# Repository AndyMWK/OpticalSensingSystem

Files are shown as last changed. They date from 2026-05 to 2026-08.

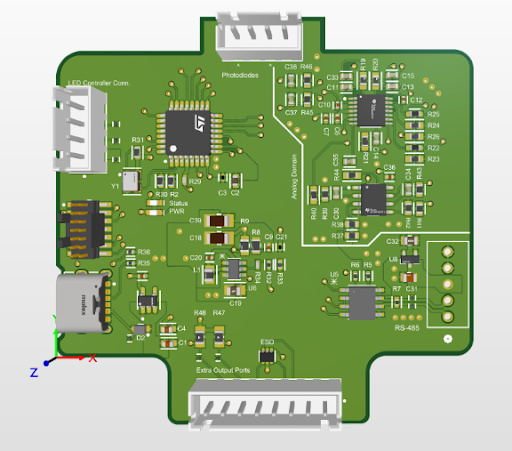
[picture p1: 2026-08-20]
Electrical/board photos/controller pcb view.png

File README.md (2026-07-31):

# IR Sensor Project

An IR proximity/distance sensing system built around dual photodiodes, covering both the electrical hardware and the firmware that drives it.



## Electrical

Designed in Altium ([Electrical/board design](Electrical/board%20design)), the board integrates an IR LED emitter with a dual-photodiode receiver front end, an analog TIA (transimpedance amplifier) stage, USB and RS485 communication interfaces, and power regulation. Analog behavior is validated with SPICE simulations under `Electrical/analog spice simulations`, and datasheets/design docs are kept under `Electrical/Datasheets` and `Electrical/Design Docs`.

## Firmware

The firmware ([Firmware/](Firmware/)) runs on STM32 microcontrollers (mock/dev target: STM32F030R8, production target: STM32G030) and handles ADC acquisition via DMA, EMA low-pass filtering, distance conversion, a finite state machine for sensor status/error handling, and RS485/UART communication. See [Firmware/Doc.md](Firmware/Doc.md) for a detailed architecture overview.

The build tooling is just **STM32CubeMX** for peripheral/HAL code generation, with custom application-level APIs layered on top — no additional framework or RTOS. A Python GUI ([Firmware/gui](Firmware/gui)) is included for interacting with and visualizing sensor data over the host machine.

### Platform support

Currently Windows-only. Linux and macOS support is not implemented yet.

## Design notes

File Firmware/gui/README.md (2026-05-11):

# IR Sensor UART GUI

Basic Python GUI for the `ir_sensor_mock` UART logger.

The mock firmware emits lines like:

```text
PD0 D:1.23 T:45s PD1 D:1.20 T:45s
```

The GUI opens the first available serial port at `9600` baud, shows incoming UART text, and plots the PD0/PD1 distance values.

## Run

```powershell
python -m pip install -r requirements.txt
python ir_sensor_gui.py
```

Use **Refresh** if you connect the board after opening the app.

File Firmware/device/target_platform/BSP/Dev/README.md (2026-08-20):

Device Drivers and APIs for commonly used devices.

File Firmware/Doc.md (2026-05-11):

# IR Sensor Firmware Design Overview

## Introduction

This document provides a brief design overview of the IR sensor firmware implemented in the mock directory (`mock/nucleof030r8/ir_sensor_mock/`). The mock firmware serves as a prototype for the actual target device firmware, utilizing the same core inner workings and architecture. The firmware is designed for STM32F030 microcontroller and simulates IR sensor functionality using two photodiodes.

## Architecture

The firmware follows a modular architecture built on STM32CubeMX-generated code with custom modules for sensor processing. Key components include:

- **Microcontroller**: Mock Device: STM32F030R8 Target Device: STM32G030
- **Peripherals**: ADC (with DMA), UART1/UART2, TIM1/TIM3, RTC
- **Communication**: RS485 for sensor data transmission, UART for logging/debugging
- **Power Management**: Basic HAL-based initialization

## Core Modules

### 1. IR ADC Module (`ir_adc.c`)
- Initializes ADC peripheral with DMA for continuous conversion
- Handles two photodiode channels (PHOTODIODE_1, PHOTODIODE_2)
- Provides callback mechanism for conversion completion
- Packs ADC readings with timestamps into message structures

### 2. IR Processing Module (`ir_processing.c`)
- Converts raw ADC values to distance measurements
- Implements Exponential Moving Average Low Pass Filter (EMA LPF) for noise reduction
- Processes data from FIFO buffers
- Handles sensor status detection (OK, saturated, out of range)

### 3. FIFO Module (`fifo.c`)
- Provides circular buffer implementation for ADC data queuing
- Supports enqueue/dequeue operations for message passing between modules
- Used to decouple ADC acquisition from processing

### 4. Finite State Machine (FSM) Module (`fsm.c`)
- Manages sensor operational states (IDLE, ACTIVE, ERROR)
- Processes incoming data and communication messages
- Handles error conditions and recovery
- Generates output messages for transmission

### 5. Communication Modules
- **RS485 Module**: Handles Modbus-style communication protocol
- **Logger Module**: Provides debug logging via UART

## Data Flow

1. **ADC Acquisition**: Timer-triggered ADC conversions read photodiode voltages via DMA
2. **Buffering**: ADC values with timestamps are enqueued into FIFO buffers
3. **Processing**: FSM dequeues data, applies EMA LPF filtering, converts to distances
4. **State Management**: FSM evaluates sensor status and handles errors
5. **Output**: Processed data is formatted and transmitted via RS485/UART

## Key Features

- **Real-time Processing**: Interrupt-driven ADC with DMA for low-latency acquisition
- **Noise Filtering**: EMA LPF reduces sensor noise for stable distance measurements
- **Error Handling**: Comprehensive status checking and error recovery
- **Modular Design**: Clean separation of concerns for maintainability
- **Communication**: Dual UART interfaces for logging and data transmission

## Build System

- **CMake-based**: Cross-platform build configuration
- **Toolchains**: GCC ARM None EABI, ST ARM Clang
- **STM32CubeMX Integration**: Automated peripheral configuration

This design provides a robust foundation for IR distance sensing applications, with the mock implementation serving as a development and testing platform for the production firmware.

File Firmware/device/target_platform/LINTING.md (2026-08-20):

# Linting this project

`clang-format` and `clang-tidy` run as pre-commit hooks (see `.pre-commit-config.yaml` at
the repo root). They are scoped to hand-written code only:

| In scope | Out of scope |
| --- | --- |
| `Core/Src/modules/*.c` | `Core/Src/{main,stm32g0xx_it,stm32g0xx_hal_msp,syscalls,sysmem,system_stm32g0xx}.c` |
| `Core/Inc/*.h` (ours) | `Core/Inc/{main,stm32g0xx_it,stm32g0xx_hal_conf}.h` |
| `BSP/**` | `Drivers/**` (CMSIS + STM32 HAL) |
| `tests/**` (clang-format only) | `Firmware/device/gen2_fw`, `Firmware/mock` |

CubeMX-generated and vendor files are excluded because CubeMX rewrites them on regeneration
and their naming is ST's, not ours.

## `compile_flags.txt`

clang-tidy has to parse a full translation unit, so it needs the cross-compile flags. There
is no `compile_commands.json` available at commit time — CMake writes it to `build/Debug/`,
which is gitignored, and the hook only looks for it in `build/`, `out/`, `cmake-build-debug/`
and `_build/` relative to the *repo root*.

Instead, `compile_flags.txt` sits at the root of this project. clang-tidy's
`FixedCompilationDatabase` walks up from each source file until it finds one, so it applies
to everything under `target_platform/` with no build step and no CI dependency. Paths inside
it resolve relative to its own directory.

Without it you get ~20 hard errors per file: `'fsm.h' file not found`,
`cmsis_compiler.h: Unknown compiler.`, `unknown type name '__STATIC_INLINE'`. The
`--target=arm-none-eabi` line fixes the CMSIS ones; `--sysroot` is what lets `<string.h>`
and friends resolve.

### ⚠ The `--sysroot` line is machine-specific

```
--sysroot=C:/ST/STM32CubeCLT_1.19.0/GNU-tools-for-STM32/arm-none-eabi
```

That is the newlib installation shipped with STM32CubeCLT on this workstation. On any other
machine — different CubeCLT version, different install path, Linux — **edit this one line**.
Find the right value with:

```
arm-none-eabi-gcc -print-sysroot
```

`compile_flags.txt` has no comment syntax (every line is passed to the compiler verbatim),
which is why this warning lives here instead of inline.

### Keeping the include list current

The `-D` and `-I` lines mirror `MX_Defines_Syms` and `MX_Include_Dirs` in
`cmake/stm32cubemx/CMakeLists.txt`, plus `BSP/Dev/Inc` and `BSP/Port/Inc`, which are not in
the CMake build yet. If CubeMX adds an include path or a symbol, mirror it here too.

## Tool versions

`--version=22.1.8` is pinned on both hooks in `.pre-commit-config.yaml`. Left unpinned, the
hook re-resolves the newest wheel from PyPI on every run and pip-installs it, which races
across parallel hook processes and fails with `Access is denied` on Windows. The cost of
pinning is that the hooks need network access to validate the version — they will not run
offline. To bump, change the version in both `args:` lists and run
`pre-commit clean && pre-commit install --install-hooks`.

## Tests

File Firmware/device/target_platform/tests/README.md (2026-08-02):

# Host-side unit tests

These tests compile the hardware-independent firmware modules with your PC's
compiler and run them as ordinary programs. No board, no debugger, no flashing
— the whole suite runs in about a third of a second.

```
ctest --test-dir build/host-tests --output-on-failure
```

---

## 1. Running them

The MSYS2 UCRT64 toolchain is not on the system `PATH`, so put it there for the
session first:

```powershell
$env:PATH = "C:\msys64\ucrt64\bin;$env:PATH"
```

Then, from the `ir_sensor_mock` directory:

```powershell
cmake -S tests -B build/host-tests -G Ninja   # configure (only after changing CMake files)
cmake --build build/host-tests                # compile
ctest --test-dir build/host-tests --output-on-failure
```

Day to day you only need the last two. Useful variations:

| Command | What it does |
| --- | --- |
| `ctest --test-dir build/host-tests -R fsm` | Run only suites matching "fsm" |
| `ctest --test-dir build/host-tests -V` | Show every assertion, not just failures |
| `.\build\host-tests\src\test_fsm.exe` | Run one suite directly — the fastest edit/run loop |

To make the toolchain permanent instead of per-session, add
`C:\msys64\ucrt64\bin` to your user `PATH` in Windows environment variables.

---

## 2. The four pieces, and why each exists

### Piece 1 — a second, separate CMake project

`../CMakeLists.txt` builds the firmware, and `../CMakePresets.json` pins it to
`cmake/gcc-arm-none-eabi.cmake`. Everything it produces is Cortex-M0 machine
code, which your PC cannot execute.

So `tests/CMakeLists.txt` is its own `project()` with **no toolchain file**.
CMake falls back to the native compiler, and the output is a normal `.exe`.
Same source files, two different compilers, two different build directories.
The firmware build is completely untouched by any of this.

```
ir_sensor_mock/
├── CMakeLists.txt          ── firmware  → arm-none-eabi-gcc → .elf
└── tests/
    └── CMakeLists.txt      ── tests     → gcc               → .exe
```

### Piece 2 — the HAL stub

This is the part that takes the most explaining, because it looks like a hack
until you see the constraint.

Every module header starts with `#include "main.h"`, and `Core/Inc/main.h`
starts with `#include "stm32f0xx_hal.h"`. That HAL header only compiles for ARM.

The obvious fix — put a different `main.h` earlier on the include path —
does not work. When `fsm.h` writes `#include "main.h"` with **quotes**, the
compiler searches `fsm.h`'s own directory first. `Core/Inc/main.h` always wins,
no matter what `-I` flags you pass.

So `fakes/hal_stub.h` does two things instead:

1. **`#define __MAIN_H`** — that is `main.h`'s own include guard. By the time
   the real `main.h` is reached, its `#ifndef __MAIN_H` is already false and the
   entire file, HAL include and all, evaluates to nothing.
2. **Supplies the handful of HAL type names** the module headers still mention
   (`UART_HandleTypeDef`, `ADC_HandleTypeDef`, …) as empty structs, since they
   are only ever used as pointers.

The stub is injected with GCC's `-include` flag (set in `tests/CMakeLists.txt`),
which processes a header before line 1 of every `.c` file. Nothing in `Core/`
is edited, and the ARM build never sees any of it.

**When you hit "unknown type name" after adding a module to the tests**, the
answer is almost always: add a minimal stand-in to `fakes/hal_stub.h`.

### Piece 3 — Unity, the test framework

[Unity](https://github.com/ThrowTheSwitch/Unity) is a small C assertion library
built for embedded work — pure C99, no C++, no dynamic allocation, small enough
to also run on the target later if you want to.

You do not need to install it. `FetchContent` in `tests/CMakeLists.txt`
downloads a pinned release at configure time and caches it under
`build/host-tests/_deps`.

A Unity test file has a fixed shape:

```c
#include "unity.h"

void setUp(void)    { /* runs before EVERY test */ }
void tearDown(void) { /* runs after  EVERY test */ }

void test_something_specific(void)
{
    TEST_ASSERT_EQUAL_UINT16(1234, actual);
}

int main(void)
{
    UNITY_BEGIN();
    RUN_TEST(test_something_specific);
    return UNITY_END();     // returns the failure count
}
```

`setUp` and `tearDown` are mandatory — Unity calls them by name and the link
fails if they are missing. There is no automatic test discovery in C, so each
test must be listed in `RUN_TEST`. Forgetting that line is the single most
common way to end up with a test that silently never runs.

Assertions used in this suite:

| Macro | Use |
| --- | --- |
| `TEST_ASSERT_EQUAL_UINT8/16/32` | Integers, with the width spelled out |
| `TEST_ASSERT_EQUAL_INT` | Enums (`sensor_status_t`, `fsm_state_t`) |
| `TEST_ASSERT_FLOAT_WITHIN(tol, expected, actual)` | Floats — never compare with `==` |
| `TEST_ASSERT_EQUAL_STRING` | Whole-string match |
| `TEST_ASSERT_TRUE` / `_NULL` / `_NOT_NULL` | Everything else |
| `TEST_FAIL_MESSAGE("...")` | Custom failure text |

### Piece 4 — CTest, the runner

`add_test()` in `src/CMakeLists.txt` registers each executable with CTest.
The contract is just the process exit code: `0` means pass. `UNITY_END()`
returns the number of failures, so this wires up with no glue code.

One executable per test file is deliberate. `fsm.c` and `ir_processing.c` both
hold state in file-scope `static` variables, and a separate process per file
guarantees that state cannot leak between files.

---

## 3. Adding a test

**A new case in an existing suite** — write the function, then add its
`RUN_TEST(...)` line in `main()`. Nothing else.

**A new suite** — drop `test_<module>.c` in `src/`, and add its filename to
`TEST_SOURCES` in `src/CMakeLists.txt`. Re-run the `cmake -S tests -B ...`
configure step so CMake picks up the new file.

**A new module under test** — add its `.c` to `fw_under_test` in
`tests/CMakeLists.txt`. If it calls HAL functions directly (`logger.c`,
`rs485.c` and `ir_adc.c` all do), you first need to give the linker a
definition for each one. Write a `fakes/hal_fake.c` with a recording
implementation — the same spy pattern `test_fsm.c` already uses for its
callbacks:

```c
/* in fakes/hal_fake.c */
int hal_uart_transmit_calls;

HAL_StatusTypeDef HAL_UART_Transmit(UART_HandleTypeDef *h, uint8_t *d,
                                    uint16_t size, uint32_t timeout)
{
    (void)h; (void)d; (void)size; (void)timeout;
    hal_uart_transmit_calls++;
    return 0;
}
```

...then add that file to the `fw_under_test` sources and the matching type
declarations to `hal_stub.h`.

---

## 4. Notes on what is actually tested

**44 tests across 3 suites.**

`test_fifo.c` (9) — pure logic, no hidden state, the easiest module to test and
the best one to read first. Covers ordering, capacity, the overwrite-oldest
overflow policy, index wraparound and NULL guards.

`test_ir_processor.c` (14) — the ADC-to-distance model, the saturation and
out-of-range thresholds (including the exact boundary values), and the EMA
filter's step response.

`test_fsm.c` (21) — state transitions, log output, the closed-loop PWM
brightness control, RS485 command handling and the async log handoff.

### Two testability problems these tests had to work around

Both are worth knowing about, because they are the kind of thing that only
becomes visible once you try to write the first test.

**1. `ir_processing.c`'s EMA cache cannot be reset.** `static ema_lpf_cache_t
ema_mem` persists for the life of the process and has no public reset. A test
that assumed the filter started at zero would pass or fail depending on which
test ran before it. The workaround is `settle_ema_at()` — drive the filter to a
known level first. The proper fix is a small `void ir_processing_reset(void);`
in the module, called from `setUp()`.

**2. `reset_fsm()` does not reset everything.** It clears `ctx` and the UART
buffer, but not `ir_led_pwm` (so the duty cycle carries between tests) and not
`async_signal`. The tests handle this by draining the async signal in `setUp()`
and by asserting on *relative* duty-cycle change rather than absolute values.

### Two firmware issues the tests surfaced

**`update_fsm()` erases RS485 acknowledgements before they can be sent.**
`update_state_rs485_cmd()` appends the reply to `output_msg.uart_tx`, then a few
lines later `update_fsm()` runs `memset(output_msg.uart_tx, 0, ...)` before
building the data log. Every acknowledgement is lost except `STREAM_DISABLE`,
which survives only because `STATE_STREAMING_DISABLED` skips that block.
`test_rs485_acknowledgement_is_lost_when_the_data_log_resumes` pins the current
behaviour and explains how to invert it once the `memset` is moved to the top
of `update_fsm()`.

**`STATE_ERROR` is unreachable.** It is only entered from
`handle_sensor_error()`, which only runs on `SENSOR_RATE_LIMIT` — and
`ir_processing.c` never returns that status, because `verify_rate_limit()` is
still commented out. So `MAX_ERROR_COUNT` currently has no terminal state to
escalate to. Noted in
`test_repeated_empty_fifos_eventually_latch_the_error_state`.

There is also a `/* just for debugging */` line in the `STATE_IDLE` branch of
`fsm.c` that forces `STATE_STREAMING` regardless of the RS485 command.
`test_idle_transitions_to_streaming_on_the_first_update` documents it so it is
not shipped by accident.

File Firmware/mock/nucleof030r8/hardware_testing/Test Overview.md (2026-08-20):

# Hardware Test Overview

## Setup

- **DUT:** ST Nucleo-F030R8 running the IR sensor firmware (FSM + PWM control loop).
- **Stimulus/measurement instrument:** Digilent Analog Discovery 2 (AD2), connected via flying leads to the Nucleo's Arduino header (photodiode ADC inputs, PWM output, ground reference).

The AD2's power supplies / AWG channels are used to source static DC voltages into the two photodiode input channels (PD1/PD2), standing in for the analog signal the IR photodiode front-end would normally produce at a given target distance. The AD2's scope channels are used to monitor the resulting PWM output from the Nucleo.

## What's being tested

The firmware's FSM (`fsm.c`) classifies the photodiode signal on every sample against two thresholds:

- **Saturation** — ADC reading above `SATURATION_LIMIT` (~3.2 V), meaning the target is too close and the sensor front-end is clipping.
- **Too far** — ADC reading below `OUT_OF_RANGE_LIMIT` (~40 mV), meaning the target is too far and the return signal is too weak to trust.

When either condition is detected, the FSM drives the IR LED PWM duty cycle toward a compensation target instead of leaving it fixed:

- `STATE_SATURATION` → `STATE_PWM_DIM`, ramping duty cycle down toward `PWM_DIM_TARGET` (35%) in `PWM_DELTA` (1%) steps.
- `STATE_TOO_FAR` → `STATE_PWM_BRIGHTEN`, ramping duty cycle up toward `PWM_BRIGHTEN_TARGET` (65%) in the same 1% steps.

This is the same idea as active/automatic gain compensation (AGC): rather than a fixed emitter drive, the loop continuously trims LED brightness to keep the received signal in a usable range regardless of target distance.

## Procedure

1. Flash the firmware to the Nucleo and connect the AD2 leads to the PD1/PD2 analog inputs and the PWM output pin.
2. Using the AD2 (WaveForms), apply a static DC voltage above the saturation threshold to a photodiode input and confirm:
   - FSM transitions into `STATE_SATURATION` then `STATE_PWM_DIM`.
   - PWM duty cycle steps downward, 1% per FSM tick, converging on 35%.
3. Sweep/step the DC input down through the out-of-range threshold and confirm:
   - FSM transitions into `STATE_TOO_FAR` then `STATE_PWM_BRIGHTEN`.
   - PWM duty cycle steps upward, 1% per FSM tick, converging on 65%.
4. Apply a DC voltage between the two thresholds and confirm the FSM holds `STATE_STREAMING` with no PWM adjustment (baseline/no-compensation-needed case).
5. Capture the PWM duty cycle transition on the AD2 scope channel to verify the ramp rate and settling behavior visually.

## Video Footage
Video Link (https://youtube.com/shorts/1NGU2nRBifU)

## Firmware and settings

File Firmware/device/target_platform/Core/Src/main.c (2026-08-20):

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
/* Includes ------------------------------------------------------------------*/
#include "main.h"

/* USER CODE BEGIN Includes */
#include "bsp_spi.h"
#include "led_pwm_control.h"
/* USER CODE END Includes */

ADC_HandleTypeDef hadc1;
DMA_HandleTypeDef hdma_adc1;

I2C_HandleTypeDef hi2c1;

RTC_HandleTypeDef hrtc;

SPI_HandleTypeDef hspi1;

TIM_HandleTypeDef htim1;
TIM_HandleTypeDef htim3;
TIM_HandleTypeDef htim14;
TIM_HandleTypeDef htim16;

UART_HandleTypeDef huart1;
UART_HandleTypeDef huart2;
DMA_HandleTypeDef hdma_usart1_rx;
DMA_HandleTypeDef hdma_usart1_tx;
DMA_HandleTypeDef hdma_usart2_rx;
DMA_HandleTypeDef hdma_usart2_tx;

void SystemClock_Config(void);
static void MX_GPIO_Init(void);
static void MX_DMA_Init(void);
static void MX_ADC1_Init(void);
static void MX_I2C1_Init(void);
static void MX_SPI1_Init(void);
static void MX_TIM1_Init(void);
static void MX_TIM3_Init(void);
static void MX_USART1_UART_Init(void);
static void MX_USART2_UART_Init(void);
static void MX_RTC_Init(void);
static void MX_TIM14_Init(void);
static void MX_TIM16_Init(void);
/* USER CODE BEGIN 0 */
ir_led_pwm_t ir_led; 

/* USER CODE END 0 */

/**
 * @brief  The application entry point.
 * @retval int
 */
int main(void)
{
    /* MCU Configuration--------------------------------------------------------*/

    /* Reset of all peripherals, Initializes the Flash interface and the Systick. */
    HAL_Init();

    /* Configure the system clock */
    SystemClock_Config();

    /* Initialize all configured peripherals */
    MX_GPIO_Init();
    MX_DMA_Init();
    MX_ADC1_Init();
    MX_I2C1_Init();
    MX_SPI1_Init();
    MX_TIM1_Init();
    MX_TIM3_Init();
    MX_USART1_UART_Init();
    MX_USART2_UART_Init();
    MX_RTC_Init();
    MX_TIM14_Init();
    MX_TIM16_Init();
    /* USER CODE BEGIN 2 */
    ir_led_pwm_init(&ir_led, BSP_PWM_IR_LED);

    /* USER CODE END 2 */

    /* Infinite loop */
    /* USER CODE BEGIN WHILE */
    while (1)
    {
        /* USER CODE END WHILE */

        /* USER CODE BEGIN 3 */
    }
    /* USER CODE END 3 */
}

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
/* USER CODE BEGIN 4 */

// pipe the spi handle to the pipe/arbiter that will call the associated callback function
void HAL_SPI_TxCpltCallback(SPI_HandleTypeDef* hspi) {
    bsp_spi_tx_dma_cb_pipe(hspi);
}

/* USER CODE END 4 */
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


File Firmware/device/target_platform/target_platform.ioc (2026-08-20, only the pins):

Mcu.UserName=STM32G030K8Tx
PA0.Signal=ADC1_IN0
PA1.Signal=ADC1_IN1
PA10.Signal=USART1_RX
PA13.Signal=SYS_SWDIO
PA14-BOOT0.Signal=SYS_SWCLK
PA2.Signal=USART2_TX
PA3.Signal=USART2_RX
PA5.Signal=SPI1_SCK
PA6.Signal=SPI1_MISO
PA7.Signal=SPI1_MOSI
PA8.GPIO_Label=LED PWM
PA8.Signal=S_TIM1_CH1
PA9.Signal=USART1_TX
PB0.Signal=SPI1_NSS
PB2.GPIO_Label=LED EN
PB2.Signal=GPIO_Output
PB6.Signal=I2C1_SCL
PB7.Signal=I2C1_SDA
PC6.GPIO_Label=Status LED
PC6.Signal=GPIO_Output

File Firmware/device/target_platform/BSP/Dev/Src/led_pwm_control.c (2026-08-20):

#include "led_pwm_control.h"

static status_signal_t update_pwm_status(ir_led_pwm_t* self);

/// @brief binds an LED instance to a PWM channel and starts it.
/// @param self caller owned instance, zeroed and populated by this call
/// @param ch PWM channel to drive
/// @return DEV_OK on success. DEV_INVALID_INPUT for a NULL self,
///         DEV_CHANNEL_NOT_AVAILABLE for an unknown channel, otherwise whatever the
///         Port layer reported.
status_signal_t ir_led_pwm_init(ir_led_pwm_t* self, const bsp_pwm_t ch)
{
    if (self == NULL)
    {
        return DEV_INVALID_INPUT;
    }

    if (!CHECK_VALID_CHANNEL_PWM(ch))
    {
        return DEV_CHANNEL_NOT_AVAILABLE;
    }

    self->pwm_channel = ch;
    self->curr_duty = 0.0f;
    self->curr_freq = 0;

    hal_signal_t hw = bsp_pwm_start(self->pwm_channel);

    if (hw != HW_OK)
    {
        return dev_status_from_hal(hw);
    }

    return update_pwm_status(self);
}

/// @brief stops the PWM output on the instance's channel.
/// @param self IR LED type handle
/// @return DEV_OK on success, DEV_INVALID_INPUT for a NULL self, otherwise whatever the
///         Port layer reported.
status_signal_t ir_led_pwm_stop(ir_led_pwm_t* self)
{
    if (self == NULL)
    {
        return DEV_INVALID_INPUT;
    }

    hal_signal_t hw = bsp_pwm_stop(self->pwm_channel);
    if (hw != HW_OK)
    {
        return dev_status_from_hal(hw);
    }

    return update_pwm_status(self);
}

/// @brief raises the duty cycle by increment.
/// @param self IR LED type handle
/// @param increment percentage points to add. Must be strictly positive.
/// @return DEV_OK on success. DEV_INVALID_INPUT for a NULL self, a non-positive or NaN
///         increment, or a step that would reach IR_LED_MAX_DUTY.
status_signal_t ir_led_pwm_brighten(ir_led_pwm_t* self, const float increment)
{
    if (self == NULL)
    {
        return DEV_INVALID_INPUT;
    }

    /* Written negated so NaN is rejected too. Without this a negative increment slips
       past the IR_LED_MAX_DUTY check below and dims straight through the IR_LED_MIN_DUTY floor. */
    if (!(increment > 0.0f))
    {
        return DEV_INVALID_INPUT;
    }

    if (self->curr_duty + increment >= IR_LED_MAX_DUTY)
    {
        return DEV_INVALID_INPUT;
    }

    hal_signal_t hw = bsp_pwm_set_duty_percent(self->pwm_channel, self->curr_duty + increment);

    if (hw != HW_OK)
    {
        return dev_status_from_hal(hw);
    }

    return update_pwm_status(self);
}

/// @brief lowers the duty cycle by decrement.
/// @param self IR LED type handle
/// @param decrement percentage points to subtract. Must be strictly positive.
/// @return DEV_OK on success. DEV_INVALID_INPUT for a NULL self, a non-positive or NaN
///         decrement, or a step that would reach IR_LED_MIN_DUTY.
status_signal_t ir_led_pwm_dim(ir_led_pwm_t* self, const float decrement)
{
    if (self == NULL)
    {
        return DEV_INVALID_INPUT;
    }

    // see the note in ir_led_pwm_brighten
    if (!(decrement > 0.0f))
    {
        return DEV_INVALID_INPUT;
    }

    if (self->curr_duty - decrement <= IR_LED_MIN_DUTY)
    {
        return DEV_INVALID_INPUT;
    }

    hal_signal_t hw = bsp_pwm_set_duty_percent(self->pwm_channel, self->curr_duty - decrement);

    if (hw != HW_OK)
    {
        return dev_status_from_hal(hw);
    }

    return update_pwm_status(self);
}

/// @brief reads back the duty cycle the channel is currently running at.
/// @param self IR LED type handle
/// @param status optional out param carrying the reason for a failed read
/// @return duty cycle as a percentage, or 0.0f on failure. 0.0f is also a legitimate
///         reading, so pass status if the caller needs to tell the two apart.
float ir_led_pwm_get_duty(ir_led_pwm_t* self, status_signal_t* status)
{
    const status_signal_t s = update_pwm_status(self);

    if (status != NULL)
    {
        *status = s;
    }

    // s is never DEV_OK when self is NULL, so the dereference is guarded
    return (s == DEV_OK) ? self->curr_duty : 0.0f;
}

/// @brief reads back the frequency the channel is currently running at.
/// @param self IR LED type handle
/// @param status optional out param carrying the reason for a failed read
/// @return frequency in Hz, or 0 on failure. 0 is also what a stopped timer reads, so
///         pass status if the caller needs to tell the two apart.
uint32_t ir_led_pwm_get_freq(ir_led_pwm_t* self, status_signal_t* status)
{
    const status_signal_t s = update_pwm_status(self);

    if (status != NULL)
    {
        *status = s;
    }

    // s is never DEV_OK when self is NULL, so the dereference is guarded
    return (s == DEV_OK) ? self->curr_freq : 0u;
}

/// @brief manually sets the IR LED duty cycle directly
/// @param self IR LED type handle
/// @param duty duty cycle
/// @return device status
status_signal_t ir_led_override_duty(ir_led_pwm_t* self, const float duty)
{
    if (!CHECK_VALID_CHANNEL_PWM(self->pwm_channel))
    {
        return DEV_CHANNEL_NOT_AVAILABLE;
    }

    if (duty > IR_LED_MAX_DUTY || duty < IR_LED_MIN_DUTY)
    {
        return DEV_INVALID_INPUT;
    }

    hal_signal_t hw = bsp_pwm_set_duty_percent(self->pwm_channel, duty);

    if (hw != HW_OK)
    {
        return dev_status_from_hal(hw);
    }

    // calling update_pwm_status is more expensive so if the bsp call was successful
    // the duty can just be set from the received duty value.
    self->curr_duty = duty;

    return DEV_OK;
}

/// @brief refreshes the cached duty and frequency from the hardware.
/// @param self instance to refresh
/// @return DEV_OK if both reads succeeded, otherwise the mapped reason for the first
///         one that failed.
static status_signal_t update_pwm_status(ir_led_pwm_t* self)
{
    if (self == NULL)
    {
        return DEV_INVALID_INPUT;
    }

    hal_signal_t duty_status = HW_OK;
    hal_signal_t freq_status = HW_OK;

    self->curr_duty = bsp_pwm_get_duty_percent(self->pwm_channel, &duty_status);

    if (duty_status != HW_OK)
    {
        return dev_status_from_hal(duty_status);
    }

    self->curr_freq = bsp_pwm_get_freq_hz(self->pwm_channel, &freq_status);

    if (freq_status != HW_OK)
    {
        return dev_status_from_hal(freq_status);
    }

    return DEV_OK;
}

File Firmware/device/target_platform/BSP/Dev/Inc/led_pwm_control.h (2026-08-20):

#ifndef LED_PWM_CONTROL_H
#define LED_PWM_CONTROL_H

#include "signals.h"
#include "bsp_pwm.h"
#include "bsp_timer.h"

#define IR_LED_MAX_DUTY 90.0f
#define IR_LED_MIN_DUTY 10.0f

// define behaviour between electrical PWM constraint and device/policy contstraint
_Static_assert(IR_LED_MAX_DUTY < BSP_DUTY_CYCLE_CAP,
               "IR LED Max Duty Cycle is greater than electrical PWM constraints");

#define IR_LED_DUTY_RAMP_UP_DELTA 1
#define IR_LED_DUTY_RAMP_DOWN_DELTA 1

/// @brief One IR LED channel. The caller owns the instance; pass the same one to every
///        call. Treat the fields as read only - they are a cache of what the hardware
///        last reported, refreshed on every call, not a place to write a new setpoint.
///
/// Not ISR safe. ir_led_pwm_brighten and ir_led_pwm_dim are read-modify-write sequences
/// over self, so a single instance must be driven from one execution context.
typedef struct ir_led_pwm_t
{
    bsp_pwm_t pwm_channel;

    // timer channel

    float curr_duty;
    uint32_t curr_freq;

} ir_led_pwm_t;

status_signal_t ir_led_pwm_init(ir_led_pwm_t* self, const bsp_pwm_t ch);
status_signal_t ir_led_pwm_stop(ir_led_pwm_t* self);

/* Both getters take an optional status out param. On failure they return 0, which is not
   distinguishable from a genuine 0% / 0 Hz reading - pass a status pointer if the caller
   needs to tell those apart. */
float ir_led_pwm_get_duty(ir_led_pwm_t* self, status_signal_t* status);
uint32_t ir_led_pwm_get_freq(ir_led_pwm_t* self, status_signal_t* status);

/* Notes:
    Deltas must be strictly positive. A step that would cross IR_LED_MAX_DUTY / IR_LED_MIN_DUTY is
    rejected rather than clamped, so the caller decides what to do at the limit.
*/
status_signal_t ir_led_pwm_brighten(ir_led_pwm_t* self, const float increment);
status_signal_t ir_led_pwm_dim(ir_led_pwm_t* self, const float decrement);

status_signal_t ir_led_override_duty(ir_led_pwm_t* self, const float duty);

status_signal_t ir_led_pwm_max_brightness(ir_led_pwm_t* self, uint16_t increment,
                                          uint16_t ramp_time);
status_signal_t ir_led_pwm_min_brightness(ir_led_pwm_t* self, uint16_t decrement,
                                          uint16_t ramp_time);


#endif

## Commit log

2026-04-11 first commit on revised board design with all elements on one board
    [IR_LED.SchDoc, IR_Sensor.SchDoc, IR_Sensor_Array.PrjPcb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]
2026-04-15 routing changes + op amp change
    [IR_LED.SchDoc, IR_Sensor.SchDoc, Sensor_Controller.SchDoc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]
2026-04-15 fresh monorepo
    [IR_LED.SchDoc, IR_Sensor.SchDoc, IR_Sensor_Array.PrjPcb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]
2026-04-26 added some board changes
    [Sensor_Controller.SchDoc]
2026-04-29 removed usb-uart bridge
    [IR_Sensor_Array.PrjPcb, Sensor_Controller.SchDoc, USB.SchDoc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]
2026-04-30 board changes + firmware setup
    [IR_LED.SchDoc, Sensor_Controller.SchDoc, USB.SchDoc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]
2026-05-02 schematic clean up and silk screen
    [IR_Sensor.SchDoc, Sensor_Controller.SchDoc]
2026-05-12 pcb layout changes
    [Sensor_Controller.SchDoc, comms_interface.SchDoc]
2026-05-13 layout and routing for DFM
    [IR_Sensor_Array.PrjPcb, Power.SchDoc, USB.SchDoc]
2026-07-26 added new board design
    [IR_Sensor.SchDoc, IR_Sensor_Array.PrjPcb]
2026-07-30 board design edits for the RS485 control signals
    [Sensor_Controller.SchDoc, comms_interface.SchDoc]
2026-07-30 added rs485 interface and bug fixes
    [fifo.c, fsm.c, fsm.h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]
2026-07-31 fixed bugs with uart console and tightened fsm functions
    [fsm.c, fsm.h, ir_processing.c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]
2026-07-31 added double buffering for ADC dma callbacks
2026-08-01 fixed ADC DMA data width bug, implemented double buffering on the ADC and some FSM and IR processor improvements
    [fsm.c, fsm.h, ir_processing.c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]
2026-08-01 adc double buffering fix + adc dma data width fix + fsm/ir processor improvements
2026-08-01 updating board design and LTSpice simulation files
    [IR_Sensor.SchDoc]
2026-08-02 added fsm interface for changing pwm duty cycle
2026-08-05 ported modules to target platform and setup bsp layer for future use
    [IR LED.PcbDoc, IR LED.SchDoc, PD.PcbDoc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]
2026-08-09 updated bsp section for led pwm control and added wrappers for spi peripheral
2026-08-09 fixed bugs with led pwm controller and changed ir led api to receive its own handle
    [bsp_pwm.c, bsp_spi.c, led_pwm_control.c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]
2026-08-20 pushing final changes on the bsp branch to be merged
    [IR LED.PcbDoc, IR LED.SchDoc, ir_led_board_design.PrjPcb]

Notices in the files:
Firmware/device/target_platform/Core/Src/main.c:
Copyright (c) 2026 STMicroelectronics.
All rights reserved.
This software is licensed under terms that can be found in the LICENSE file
